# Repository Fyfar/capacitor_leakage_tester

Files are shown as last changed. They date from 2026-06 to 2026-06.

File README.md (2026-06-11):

# Capacitor Leakage Tester

> ⚠️ **Work in Progress** — this project is not yet complete.

A DIY high-sensitivity capacitor leakage current meter. Applies a selectable test
voltage to a capacitor under test and measures the resulting leakage current down
to the microamp range.

## Hardware

| Component | Part |
|---|---|
| MCU | RP2040-Zero |
| External ADC | ADS1115 (16-bit, I²C) |
| Display | HD44780 16×2 LCD (I²C) |
| Input | Rotary encoder |
| Test voltages | 10 V / 16 V / 25 V / 50 V |

KiCAD schematic and PCB files are in the [`kicad/`](kicad/) directory.

## Firmware

Built with [PlatformIO](https://platformio.org/) and the Arduino framework (Earle Philhower RP2040 core).

## Status

- [x] Schematic design
- [x] PCB layout
- [x] Firmware (core measurement loop)
- [ ] Pass/fail logic
- [ ] Testing & calibration
- [ ] Documentation

## License

[MIT](LICENSE)

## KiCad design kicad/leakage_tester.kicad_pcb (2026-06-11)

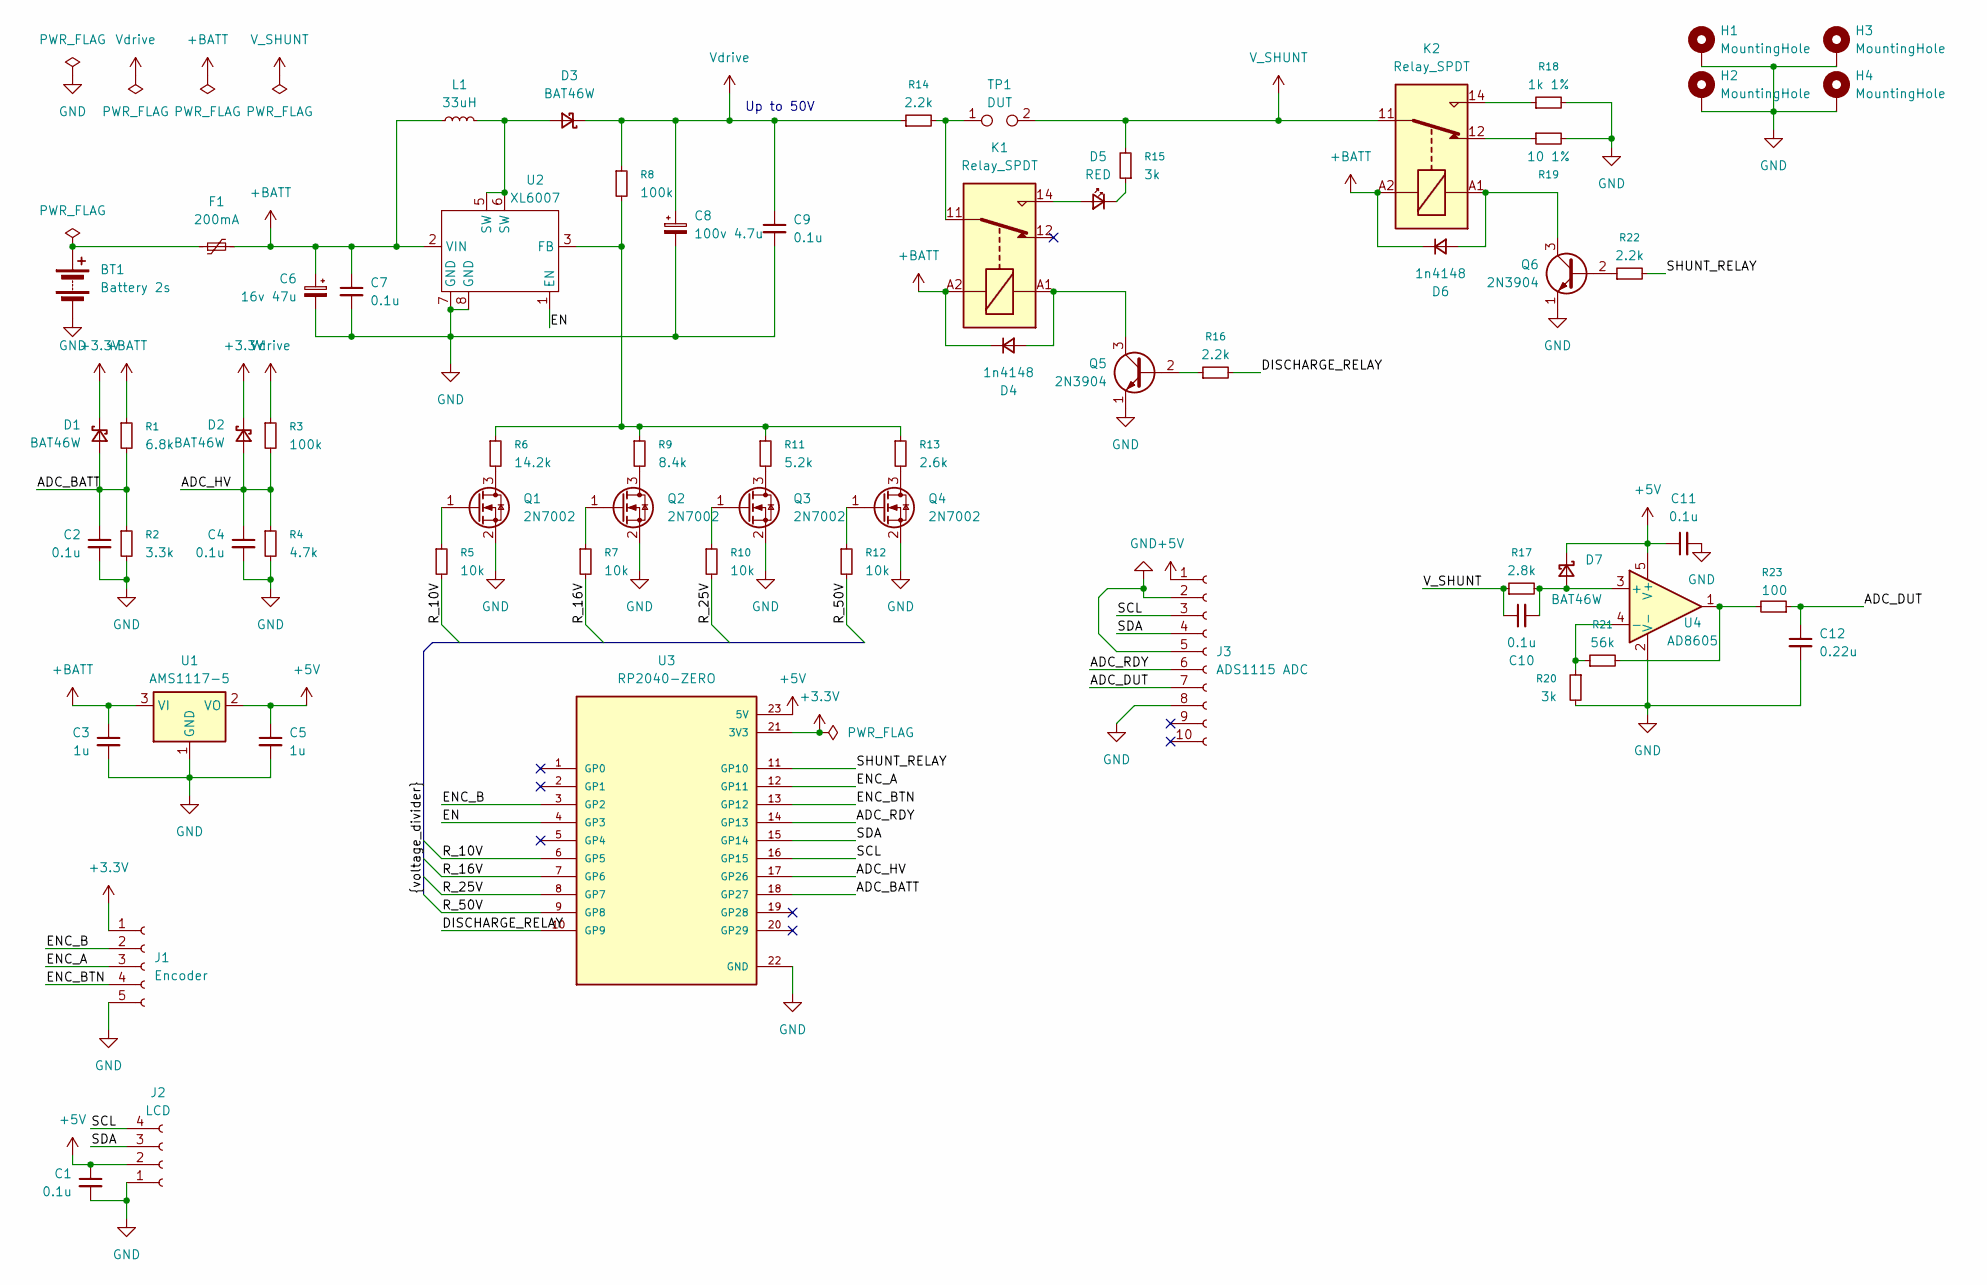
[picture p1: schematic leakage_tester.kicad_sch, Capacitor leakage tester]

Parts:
BT1: Battery 2s; PinSocket_1x02_P2.54mm_Vertical
C1, C2, C4, C7, C10, C11: 0.1u; C_0805_2012Metric_Pad1.18x1.45mm_HandSolder
C3, C5: 1u; C_0805_2012Metric_Pad1.18x1.45mm_HandSolder
C6: 16v 47u; CP_Radial_D6.3mm_P2.50mm
C8: 100v 4.7u; CP_Radial_D5.0mm_P2.50mm
C9: 0.1u; C_Rect_L7.0mm_W2.5mm_P5.00mm
C12: 0.22u; C_0805_2012Metric_Pad1.18x1.45mm_HandSolder
D1, D2, D3, D7: BAT46W; D_SOD-123
D4, D6: 1n4148; D_DO-35_SOD27_P7.62mm_Horizontal
D5: RED; LED_D3.0mm
F1: 200mA; Fuse_0805_2012Metric_Pad1.15x1.40mm_HandSolder
H1, H2, H3, H4: MountingHole; MountingHole_2.2mm_M2_Pad
J1: Encoder; PinSocket_1x05_P2.54mm_Vertical
J2: LCD; PinSocket_1x04_P2.54mm_Vertical
J3: ADS1115 ADC; PinSocket_1x10_P2.54mm_Vertical
K1, K2: Relay_SPDT; Relay_SPDT_18.4x10.2
L1: 33uH; L_Radial_D8.7mm_P5.00mm_Fastron_07HCP
Q1, Q2, Q3, Q4: 2N7002; SOT-23
Q5, Q6: 2N3904; TO-92_Inline
R1: 6.8k; R_0805_2012Metric_Pad1.20x1.40mm_HandSolder
R2: 3.3k; R_0805_2012Metric_Pad1.20x1.40mm_HandSolder
R3, R8: 100k; R_0805_2012Metric_Pad1.20x1.40mm_HandSolder
R4: 4.7k; R_0805_2012Metric_Pad1.20x1.40mm_HandSolder
R5, R7, R10, R12: 10k; R_0805_2012Metric_Pad1.20x1.40mm_HandSolder
R6: 14.2k; R_0805_2012Metric_Pad1.20x1.40mm_HandSolder
R9: 8.4k; R_0805_2012Metric_Pad1.20x1.40mm_HandSolder
R11: 5.2k; R_0805_2012Metric_Pad1.20x1.40mm_HandSolder
R13: 2.6k; R_0805_2012Metric_Pad1.20x1.40mm_HandSolder
R14, R16, R22: 2.2k; R_0805_2012Metric_Pad1.20x1.40mm_HandSolder
R15, R20: 3k; R_0805_2012Metric_Pad1.20x1.40mm_HandSolder
R17: 2.8k; R_0805_2012Metric_Pad1.20x1.40mm_HandSolder
R18: 1k 1%; R_0805_2012Metric_Pad1.20x1.40mm_HandSolder
R19: 10 1%; R_0805_2012Metric_Pad1.20x1.40mm_HandSolder
R21: 56k; R_0805_2012Metric_Pad1.20x1.40mm_HandSolder
R23: 100; R_0805_2012Metric_Pad1.20x1.40mm_HandSolder
TP1: DUT; TestPoint_2Pads_Pitch5.08mm_Drill1.3mm
U1: AMS1117-5; SOT-223-3_TabPin2
U2: XL6007; SOIC-8_3.9x4.9mm_P1.27mm
U3: RP2040-ZERO; MODULE_RP2040-ZERO; PARTREV NA
U4: AD8605; SOT-23-5

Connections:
+3.3V: D1.1 (K), D2.1 (K), J1.1, U3.21 (3V3)
+5V: C1.1, C5.1, C11.1, D7.1 (K), J2.2, J3.1, U1.2 (VO), U3.23 (5V), U4.5 (V+)
+BATT: C3.1, C6.1, C7.1, D4.1 (K), D6.1 (K), F1.2, K1.A2, K2.A2, L1.1, R1.1, U1.3 (VI), U2.2 (VIN)
/ADC_BATT: C2.1, D1.2 (A), R1.2, R2.1, U3.18 (GP27)
/ADC_DUT: C12.1, J3.7, R23.1
/ADC_HV: C4.1, D2.2 (A), R3.2, R4.1, U3.17 (GP26)
/ADC_RDY: J3.6, U3.14 (GP13)
/DISCHARGE_RELAY: R16.2, U3.10 (GP9)
/EN: U2.1 (EN), U3.4 (GP3)
/ENC_A: J1.3, U3.12 (GP11)
/ENC_B: J1.2, U3.3 (GP2)
/ENC_BTN: J1.4, U3.13 (GP12)
/R_10V: R5.2, U3.6 (GP5)
/R_16V: R7.2, U3.7 (GP6)
/R_25V: R10.2, U3.8 (GP7)
/R_50V: R12.2, U3.9 (GP8)
/SCL: J2.4, J3.3, U3.16 (GP15)
/SDA: J2.3, J3.4, U3.15 (GP14)
/SHUNT_RELAY: R22.2, U3.11 (GP10)
GND: BT1.2 (-), C1.2, C2.2, C3.2, C4.2, C5.2, C6.2, C7.2, C8.2, C9.2, C11.2, C12.2, H1.1, H2.1, H3.1, H4.1, J1.5, J2.1, J3.2, J3.5, J3.8, Q1.2 (S), Q2.2 (S), Q3.2 (S), Q4.2 (S), Q5.1 (E), Q6.1 (E), R2.2, R4.2, R18.2, R19.2, R20.2, U1.1 (GND), U2.7 (GND), U2.8 (GND), U3.22 (GND), U4.2 (V-)
unnamed: BT1.1 (+), F1.1
unnamed: D3.2 (A), L1.2, U2.5 (SW), U2.6 (SW)
unnamed: D4.2 (A), K1.A1, Q5.3 (C)
unnamed: D5.2 (A), K1.14
unnamed: D5.1 (K), R15.1
unnamed: D6.2 (A), K2.A1, Q6.3 (C)
unnamed: C10.2, D7.2 (A), R17.2, U4.3 (+)
unnamed: K1.11, R14.2, TP1.1
unnamed: K2.12, R19.1
unnamed: K2.14, R18.1
unnamed: Q1.3 (D), R6.2
unnamed: Q1.1 (G), R5.1
unnamed: Q2.3 (D), R9.2
unnamed: Q2.1 (G), R7.1
unnamed: Q3.3 (D), R11.2
unnamed: Q3.1 (G), R10.1
unnamed: Q4.3 (D), R13.2
unnamed: Q4.1 (G), R12.1
unnamed: Q5.2 (B), R16.1
unnamed: Q6.2 (B), R22.1
unnamed: R21.2, R23.2, U4.1
unnamed: R6.1, R8.2, R9.1, R11.1, R13.1, U2.3 (FB)
unnamed: R20.1, R21.1, U4.4 (-)
V_SHUNT: C10.1, K2.11, R15.2, R17.1, TP1.2
Vdrive: C8.1, C9.1, D3.1 (K), R3.1, R8.1, R14.1

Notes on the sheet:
Up to 50V

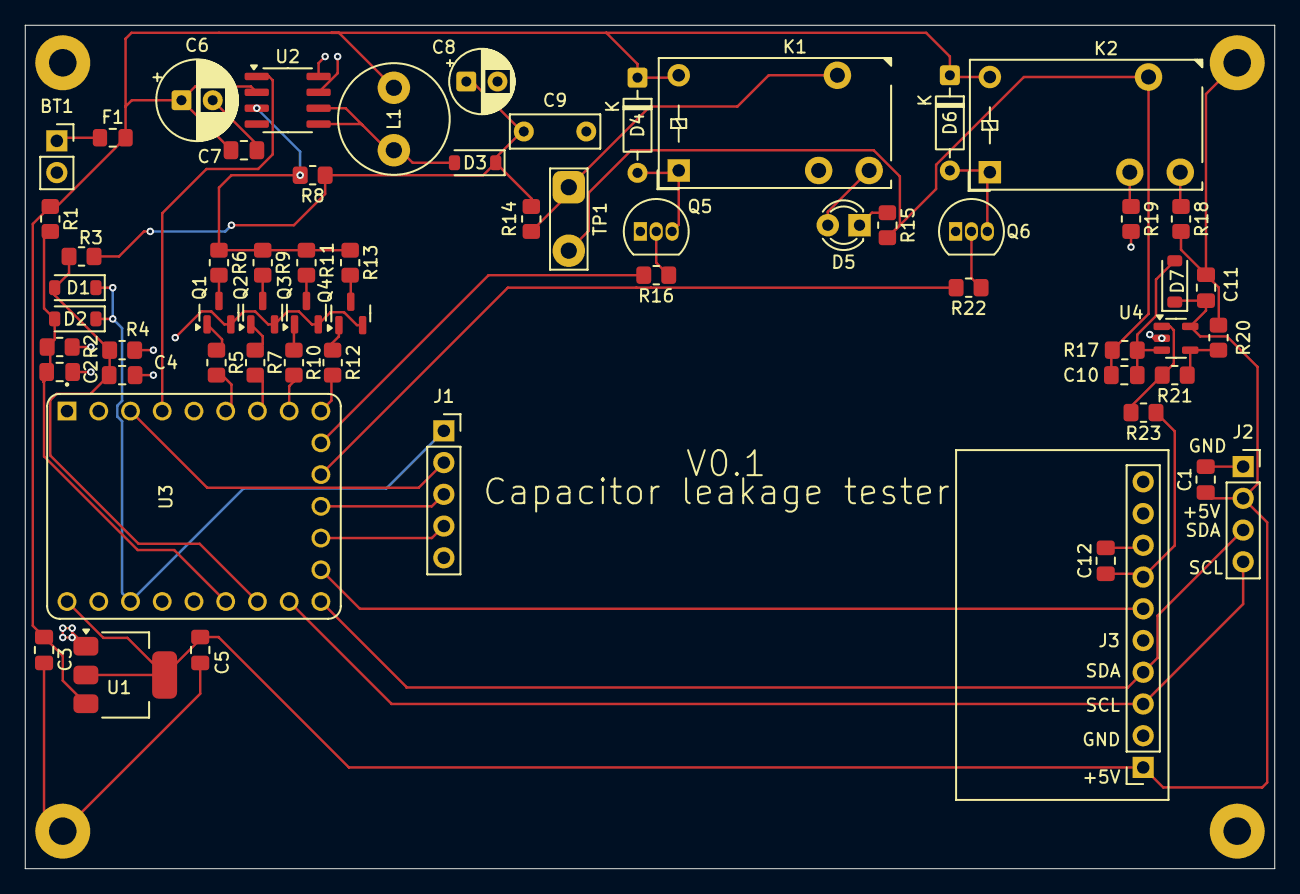
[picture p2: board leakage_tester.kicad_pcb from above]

Board: 2 copper layers, 100.0 x 67.5 mm, 65 parts (0 on the bottom side), 45 nets.

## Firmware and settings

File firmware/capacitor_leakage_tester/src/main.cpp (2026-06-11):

/**
                         ┌───────────────────────────────┐
                         │           U3                  │
                         │       RP2040-ZERO             │
                         │  1  GP0                       │
                         │  2  GP1                       │
        ENC_BTN      ───▶│  3  GP2                       │
        EN           ───▶│  4  GP3                       │
                         │  5  GP4                       │
        R_10V        ───▶│  6  GP5                       │
        R_16V        ───▶│  7  GP6                       │
        R_25V        ───▶│  8  GP7                       │
        R_50V        ───▶│  9  GP8                       │
        DISCHARGE_REL.──▶│ 10  GP9                       │
                         │ 11  GP10   ◀── SHUNT_RELAY    │
                         │ 12  GP11   ◀── ENC_A          │
                         │ 13  GP12   ◀── ENC_B          │
                         │ 14  GP13   ◀── ADC_RDY        │
                         │ 15  GP14   ◀── SDA            │
                         │ 16  GP15   ◀── SCL            │
                         │ 17  GP26   ◀── ADC_HV         │
                         │ 18  GP27   ◀── ADC_BATT       │
                         │ 19  GP28                      │
                         │ 20  GP29                      │
                         │ 21  3V3  ◀── +3.3V            │
                         │ 22  GND  ◀── GND              │
                         │ 23  5V   ◀── +5V              │
                         └───────────────────────────────┘

Notes:
- PWR_FLAG connected to +3.3V.
- ENC_A, ENC_B, ENC_BTN = rotary encoder.
- SDA/SCL = I²C bus.
- ADC_HV, ADC_BATT = ADC measurement lines.
- Relays controlled via SHUNT_RELAY and DISCHARGE_RELAY.

 */

#define EB_NO_FOR
#define EB_NO_COUNTER

#define ADC_SMOOTHING 0.5f  // smoothing factor for ADC readings

#define LOG(x) \
    if (Serial) Serial.println(x)

#include <Adafruit_ADS1X15.h>
#include <Arduino.h>
#include <EncButton.h>

#define Wire Wire1
#include <hd44780.h>
#include <hd44780ioClass/hd44780_I2Cexp.h>

EncButtonT<11, 12, 2> enc;
Adafruit_ADS1115 adc;
hd44780_I2Cexp lcd;

constexpr uint8_t LCD_COLUMNS = 16;
constexpr uint8_t LCD_ROWS = 2;

constexpr uint16_t BAT_MEASURE_PERIOD = 5000;     // ms
constexpr uint16_t OUTPUT_MEASURE_PERIOD = 250;   // period between ADC readings in ms
constexpr uint16_t LEAKAGE_MEASURE_PERIOD = 250;  // period between ADC readings in ms
constexpr uint16_t UPDATE_LCD_PERIOD = 250;       // period between LCD updates in ms
constexpr uint16_t ADC_CONVERSION_TIME = 65;      // ADC measurement each ~62.5ms

constexpr float MAX_VOLTAGE_TO_REDUCE_GAIN = 3200.0f;  // mV
constexpr float LOW_VOLTAGE_TO_INCREASE_GAIN = 43.0f;  // mV, ~200uA on low shunt

constexpr uint8_t DC_DC_ENABLE = 3;
constexpr uint8_t R_10V = 5;
constexpr uint8_t R_16V = 6;
constexpr uint8_t R_25V = 7;
constexpr uint8_t R_50V = 8;
constexpr uint8_t DISCHARGE_RELAY_PIN = 9;
constexpr uint8_t SHUNT_RELAY_PIN = 10;
constexpr uint8_t ADC_BATTERY_PIN = 27;
constexpr uint8_t ADC_OUTPUT_PIN = 26;

constexpr uint8_t dividerPins[4] = {R_10V, R_16V, R_25V, R_50V};

constexpr adsGain_t adcGain[5] = {GAIN_ONE, GAIN_TWO, GAIN_FOUR, GAIN_EIGHT, GAIN_SIXTEEN};

constexpr float BAT_DIVIDER = 2.7065f;     // ~5.1k and ~3k resistors
constexpr float OUTPUT_DIVIDER = 17.008f;  // ~75k and ~4.7k resistors 75.03 4.687
constexpr float OPAMP_AMPLIFIER_GAIN = 18.05f;
constexpr float DIOD_LEAKAGE_mV = 0.4f * OPAMP_AMPLIFIER_GAIN;  // mV
constexpr float LOW_SHUNT = 9.980f;                             // Ohm
constexpr float HIGH_SHUNT = 1000.3f;                           // Ohm

constexpr uint16_t UPPER_ADC_GAIN_LIMIT = 30000;
constexpr uint16_t LOWER_ADC_GAIN_LIMIT = UPPER_ADC_GAIN_LIMIT / 2;

uint8_t currentOutputDividerIndex = 0;

float batteryVoltage = 0.0f;
float outputVoltage = 0.0f;
float leakageCurrent = 0.0f;

unsigned long adcOutputTimer = 0;
unsigned long adcLeakageTimer = 0;
unsigned long lcdUpdateTimer = 0;

uint8_t gain = 0;

void encoderTurnISR();
void encoderButtonISR();

void encCallback();

void toggleOutput();
void setOutVoltage(uint8_t dividerPin);
void changeVoltage(int8_t direction);
void dischargeCapacitor(EBAction action);

float measureBattery();
void measureOutput();
void measureLeakage(bool force = false);
void highLeakageShuntEnable();
void lowLeakageShuntEnable();
bool isADCGainTuned(int16_t adcValue);
void updateLcd(bool force = false);

void encoderTurnISR() {
    enc.tickISR();
}

void encoderButtonISR() {
    enc.pressISR();
}

void toggleOutput() {
    digitalRead(DC_DC_ENABLE) == HIGH ? digitalWrite(DC_DC_ENABLE, LOW) : digitalWrite(DC_DC_ENABLE, HIGH);
}

void setOutVoltage(uint8_t dividerPinIndex) {
    digitalWrite(DC_DC_ENABLE, LOW);

    for (byte pin : dividerPins) {
        digitalWrite(pin, LOW);
    }
    digitalWrite(dividerPins[dividerPinIndex], HIGH);
}

void changeVoltage(int8_t direction) {
    currentOutputDividerIndex += direction;
    currentOutputDividerIndex = constrain(currentOutputDividerIndex, 0, 3);

    setOutVoltage(currentOutputDividerIndex);
    updateLcd(true);
}

void dischargeCapacitor(EBAction action) {
    if (action == EBAction::Hold) {
        digitalWrite(DISCHARGE_RELAY_PIN, HIGH);  // Activate discharge relay
        digitalWrite(DC_DC_ENABLE, LOW);          // Disable DC-DC converter while discharging
    } else if (action == EBAction::ReleaseHold) {
        digitalWrite(DISCHARGE_RELAY_PIN, LOW);  // Deactivate discharge relay
    }
}

void encCallback() {
    switch (enc.getAction()) {
        case EBAction::Click:
            LOG("Toggle output");
            toggleOutput();
            break;
        case EBAction::Hold:
            LOG("HOLD ");
            dischargeCapacitor(EBAction::Hold);
            break;
        case EBAction::ReleaseHold:
        case EBAction::ReleaseStep:
            LOG("RELEASE HOLD/STEP");
            dischargeCapacitor(EBAction::ReleaseHold);
            break;
        case EBAction::Turn:
            LOG("Turn");
            changeVoltage(enc.dir());
            break;
        default:
            break;
    }
}

float measureBattery() {
    int raw = analogRead(ADC_BATTERY_PIN);
    return (raw / 4095.0) * 3.3 * BAT_DIVIDER;
}

void measureOutput() {
    unsigned long ms = millis();

    if (ms - adcOutputTimer >= OUTPUT_MEASURE_PERIOD) {
        adcOutputTimer = ms;

        int raw = analogRead(ADC_OUTPUT_PIN);
        outputVoltage = (raw / 4095.0) * 3.3 * OUTPUT_DIVIDER;
    }
}

void highLeakageShuntEnable() {
    digitalWrite(SHUNT_RELAY_PIN, LOW);  // Turn off shunt relay
}

void lowLeakageShuntEnable() {
    digitalWrite(SHUNT_RELAY_PIN, HIGH);  // Activate shunt relay
}

bool isADCGainTuned(int16_t adcValue) {
    int16_t absValue = abs(adcValue);

    if (adcValue >= UPPER_ADC_GAIN_LIMIT && gain > 0) {
        gain--;
        adc.setGain(adcGain[gain]);
        LOG("Reducing ADC gain...");
        LOG(gain);
        return false;
    } else if (adcValue <= LOWER_ADC_GAIN_LIMIT && gain < 4) {
        gain++;
        adc.setGain(adcGain[gain]);
        LOG("Increasing ADC gain...");
        LOG(gain);
        return false;
    }

    return true;
}

void measureLeakage(bool force) {
    static unsigned long nextMeasurement = 0;
    unsigned long ms = millis();

    if (ms < nextMeasurement) return;

    int16_t adcLeakage = adc.readADC_Differential_0_1();
    if (!isADCGainTuned(adcLeakage)) {
        nextMeasurement = ms + ADC_CONVERSION_TIME;
        return;
    }

    bool isHighLeakageShunt = digitalRead(SHUNT_RELAY_PIN) == LOW;
    float voltage = adc.computeVolts(adcLeakage) * 1000.0f;  // in mV

    bool shuntSwithNeeded = false;

    if (voltage >= MAX_VOLTAGE_TO_REDUCE_GAIN && !isHighLeakageShunt) {
        highLeakageShuntEnable();
        shuntSwithNeeded = true;
        gain = 0;
        adc.setGain(adcGain[gain]);
    } else if (voltage <= LOW_VOLTAGE_TO_INCREASE_GAIN && isHighLeakageShunt) {
        lowLeakageShuntEnable();
        shuntSwithNeeded = true;
        gain = 4;
        adc.setGain(adcGain[gain]);
    }

    if (shuntSwithNeeded) {
        nextMeasurement = ms + ADC_CONVERSION_TIME + 15;  // 15 ms relay settle
        return;
    }

    if (voltage < DIOD_LEAKAGE_mV) {
        leakageCurrent = 0.0f;  // compensate diode leakage
    } else {
        float shunt = isHighLeakageShunt ? LOW_SHUNT : HIGH_SHUNT;
        leakageCurrent = (voltage - DIOD_LEAKAGE_mV) / OPAMP_AMPLIFIER_GAIN / shunt;
    }

    nextMeasurement = ms + LEAKAGE_MEASURE_PERIOD;
}

void updateLcd(bool force) {
    unsigned long ms = millis();

    if (force || (ms - lcdUpdateTimer) >= UPDATE_LCD_PERIOD) {
        lcdUpdateTimer = ms;

        lcd.setCursor(0, 0);
        lcd.print("Set:");
        switch (dividerPins[currentOutputDividerIndex]) {
            case R_10V:
                lcd.print("10V");
                break;
            case R_16V:
                lcd.print("16V");
                break;
            case R_25V:
                lcd.print("25V");
                break;
            case R_50V:
                lcd.print("50V");
                break;
            default:
                lcd.print("----");
                break;
        }
        lcd.print("  ");
        lcd.print(outputVoltage, 2);

        lcd.setCursor(0, 1);

        bool uARange = digitalRead(SHUNT_RELAY_PIN) == HIGH;

        lcd.print(leakageCurrent * (uARange ? 1000.0f : 1.0f), 2);
        lcd.print(uARange ? " uA" : " mA");
        lcd.print("  GOOD  ");
    }
}

void setup() {
    Serial.begin(115200);

    unsigned long startSerial = millis();
    while (!Serial && (millis() - startSerial < 2000)) {
        delay(10);
    }

    Wire1.setSDA(14);
    Wire1.setSCL(15);

    pinMode(DC_DC_ENABLE, OUTPUT);         // DC-DC enable
    pinMode(R_10V, OUTPUT);                // R_10V
    pinMode(R_16V, OUTPUT);                // R_16V
    pinMode(R_25V, OUTPUT);                // R_25V
    pinMode(R_50V, OUTPUT);                // R_50V
    pinMode(DISCHARGE_RELAY_PIN, OUTPUT);  // DISCHARGE_RELAY
    pinMode(SHUNT_RELAY_PIN, OUTPUT);      // SHUNT_RELAY

    pinMode(ADC_OUTPUT_PIN, INPUT);   // ADC output
    pinMode(ADC_BATTERY_PIN, INPUT);  // ADC battery
    analogReadResolution(12);         // 12-bit ADC resolution

    setOutVoltage(currentOutputDividerIndex);
    digitalWrite(DC_DC_ENABLE, LOW);  // Disable DC-DC converter
    highLeakageShuntEnable();

    attachInterrupt(digitalPinToInterrupt(11), encoderTurnISR, CHANGE);
    attachInterrupt(digitalPinToInterrupt(12), encoderTurnISR, CHANGE);
    attachInterrupt(digitalPinToInterrupt(2), encoderButtonISR, FALLING);
    enc.setEncISR(true);
    enc.attach(encCallback);
    enc.setEncType(EB_STEP4_LOW);
    enc.setBtnLevel(LOW);

    lcd.begin(LCD_COLUMNS, LCD_ROWS);
    lcd.noLineWrap();
    lcd.clear();

    adc.begin(ADS1X15_ADDRESS, &Wire1);
    adc.setDataRate(RATE_ADS1115_16SPS);
    adc.setGain(adcGain[gain]);

    lcd.setCursor(0, 0);
    float vbat = measureBattery();
    lcd.print("Battery: ");
    lcd.print(vbat, 2);
    lcd.setCursor(0, 1);
    lcd.print("Leakage tester");
    delay(3000);

    lcd.clear();

    LOG("Setup complete");
}

void loop() {
    enc.tick();

    measureOutput();
    measureLeakage();

    updateLcd();
}
